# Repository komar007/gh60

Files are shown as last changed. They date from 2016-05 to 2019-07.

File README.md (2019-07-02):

# GH60
GH60 - an open-source mechanical keyboard PCB designed for the community at [geekhack](geekhack.org).

You can read more over [here](http://blog.komar.be/projects/gh60-programmable-keyboard/).



## Geekhack threads
- [[Prototyping] GH60 Keyboard](http://geekhack.org/index.php?topic=34959.0) - free discussion and chat about the project,
- [GH60 prototype betatesting](http://geekhack.org/index.php?topic=37570.0) - revision A bug reports,
- [GH60 rev. B betatesting](http://geekhack.org/index.php?topic=50685.0) - revision B bug reports,
- [GH60 Group Buy (PRODUCTION)](http://geekhack.org/index.php?topic=41464.0) - group buy organization and chat.

## Articles
- Introduction: [Introducing the GH60 keyboard project](http://blog.komar.be/?p=267)
- Changes in rev. B: [GH60 evolution](http://blog.komar.be/gh60-evolution/)
- Release of rev. C: [GH60 rev. C "plain edition" is out](http://blog.komar.be/gh60-rev-c-plain-edition-is-out/)

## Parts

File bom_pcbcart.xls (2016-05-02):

物料清单BOM
Manufacturer生产商 | Manufacturer Part Number生产商编号 | Designator位置 | Qty数量 | Description描述(值，耐压，精度μF) | Case 封装 | SMD ,BGA,LLC(QFN),OR TH | points点数 | points | Top/Bottom顶层/底层 | 厂家 | 厂家物料号 | 描述 | 采购备注 | MOQ10 | Customer reply
AVX | 08051A220KAT2A | C1, C2 | 2 | 22pF,100V,10%,C0G,0805 | 0805 | SMD | 2 | 4 | Bottom | AVX | 08051A220KAT2A
YAGEO | CC0805KKX7R8BB105 | C3, C8 | 2 | 1uF,25V,10%,X7R,0805 | 0805 | SMD | 2 | 4 | Bottom | YAGEO | CC0805KKX7R8BB105
YAGEO | CC0805KRX7R9BB104 | C4, C5, C6, C7 | 4 | 100nF,50V,10%,X7R,0805 | 0805 | SMD | 2 | 8 | Bottom | YAGEO | CC0805KRX7R9BB104
Yageo | RC0805JR-0722RL | R1, R2 | 2 | 22R,5%,1/8W,0805 | 0805 | SMD | 2 | 4 | Bottom | Yageo | RC0805JR-0722RL
Yageo | RC0805FR-0710KL | R3, R5 | 2 | 10K,1%,1/8W,0805 | 0805 | SMD | 2 | 4 | Bottom | Yageo | RC0805FR-0710KL
Crownpo | CD4148WS | D01, D02, D03, D04, D05, D06, D07, D08, D09, D10, D11, D12, D13, D14, D15, D16, D17, D18, D19, D21, D22, D23, D24, D26, D27, D28, D29, D30, D31, D32, D33, D34, D36, D37, D38, D39, D41, D42, D43, D44, D46, D47, D48, D49, D50, D51, D52, D53, D54, D55, D56, D57, D58, D59, D60, D61, D62, D63, D64, D65, D66, D67, D68, D69, D70 | 65 | 100V,150mA,0805 | 0805 | SMD | 2 | 130 | Bottom | Crownpo | CD4148WS
NDK | NX3225GA-16MHZ- STD-CRG-2 | X1 | 1 | 16MHz,8pF,4-SMD(3.2mmL*2.5mmW*0.9mmH) | 4-SMD | SMD | 4 | 4 | Bottom | NDK | NX3225GA-16MHZ- STD-CRG-2
Atmel | ATMEGA32U4-AUR | IC1 | 1 | ATMEGA32U4-AUR,44-TQFP | 44-TQFP | SMD | 44 | 44 | Bottom | Atmel | ATMEGA32U4-AU
C&K Components | Y17K20502FP LFS | S0 | 1 | 32VDC,0.05A,6.2mmL*6.2mmW*3.1mmH | 6.2mmL*6.2mmW*3.1mmH | SMD | 4 | 4 | Bottom | C&K Components | KSEM31G LFS
Molex | 0675031020 | J1 | 1 | USB 2.0 OTG,mini B,right angle | see link | SMD | 9 | 9 | Bottom | Molex | 675031020
 |  | All components assembled on bottom side.

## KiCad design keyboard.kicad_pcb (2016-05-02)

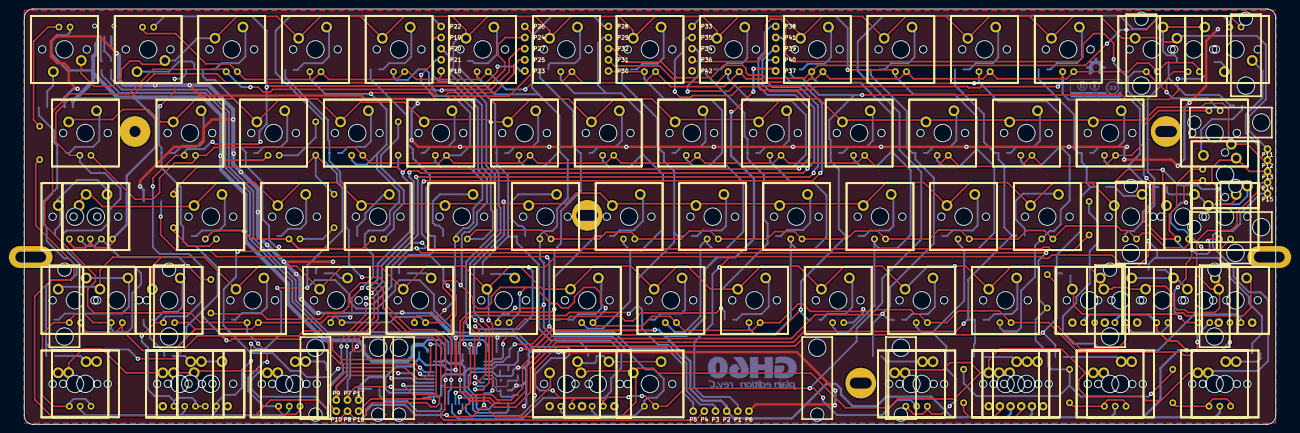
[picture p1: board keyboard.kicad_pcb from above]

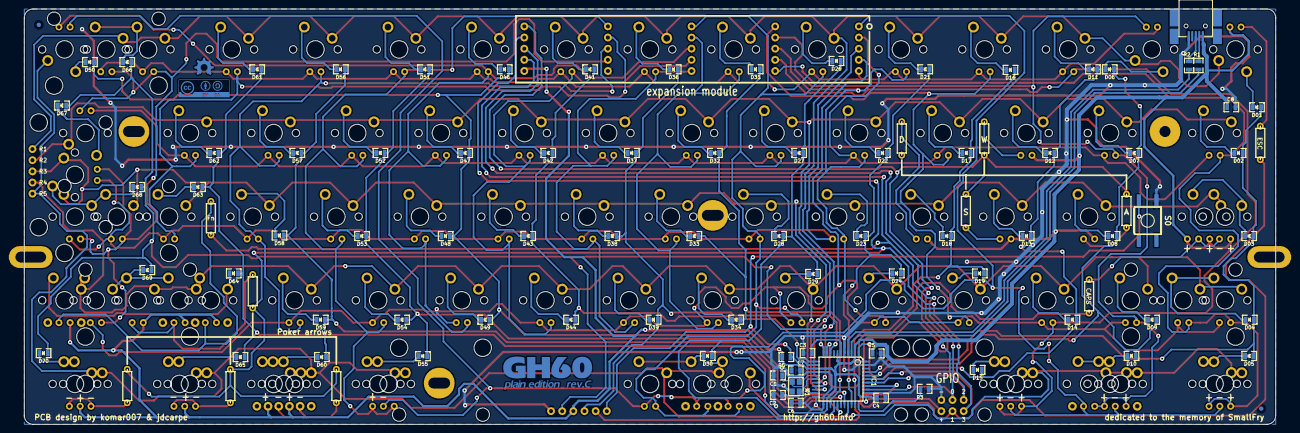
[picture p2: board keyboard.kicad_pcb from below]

Board: 2 copper layers, 285.0 x 94.6 mm, 335 parts (94 on the bottom side), 130 nets.

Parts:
C1, C2: 22p; 0805C
C3, C8: 1u; 0805C
C4, C5, C6, C7: 100n; 0805C
D01, D02, D03, D04, D05, D06, D07, D08, D09, D10, D11, D12, D13, D14, D15, D16, D17, D18, D19, D21, D22, D23, D24, D26, D27, D28, D29, D30, D31, D32, D33, D34, D36, D37, D38, D39, D41, D42, D43, D44, D46, D47, D48, D49, D50, D51, D52, D53, D54, D55, D56, D57, D58, D59, D60, D61, D62, D63, D64, D65, D66, D67, D68, D69, D70: 1N4148; 0805D
DB02, DB04, DB06, DB07, DB09, DB11, DB14, DB16, DB17, DB19, DB21, DB22, DB23, DB24, DB26, DB27, DB28, DB29, DB30, DB31, DB32, DB33, DB34, DB36, DB37, DB38, DB39, DB041, DB41, DB42, DB43, DB44, DB46, DB47, DB48, DB49, DB50, DB51, DB52, DB53, DB54, DB56, DB57, DB58, DB59, DB61, DB62, DB63, DB66, DB67, DB68, DB69, DB301, DB302, DB661, DB681, DB682: LED; MX1A-led_no3d
DB05, DB10, DB15, DB051, DB55, DB101, DB102, DB151, DB551: LEDa; MX1A-led
DC1, DC2: LED; MX1A-led_no3d
DC3: LED; MX1A-ledlock
DF3, DF10, DF11, DF20, DF201: LED; MX1A-led_no3d
DF21, DF22, DF23, DF211, DF221, DF231, DF232: LEDa; MX1A-led
DW1, DW2, DW3, DW4: LED; MX1A-led_no3d
FID: FIDUCIAL
FID#2: FIDUCIAL
HOLE: VAL**; PKRHSL
HOLE#2: VAL**; PKRHSL
HOLE#3, HOLE#4, HOLE#5: VAL**; PKRH
HOLE#6: VAL**; PKRHC
IC1: ATMEGA32U4; TQFP44
J1: MINI; 67503
MXST: VAL**; MXST
MXST#2, MXST#3, MXST#4, MXST#5, MXST#6, MXST#7, MXST#8, MXST#9, MXST#10, MXST#11, MXST#12, MXST#13, MXST#14, MXST#15: VAL**; MXST
MXWIRE: VAL**; MX1A-wire
MXWIRE#2, MXWIRE#3, MXWIRE#4, MXWIRE#5, MXWIRE#6, MXWIRE#7, MXWIRE#8, MXWIRE#9: VAL**; MX1A-wire
P1, P2, P3, P4, P5, P6, P7, P8, P9, P10, P11, P12, P13, P14, P15, P16, P17, P18, P19, P20, P21, P22, P23, P24, P25, P26, P27, P28, P29, P30, P31, P32, P33, P34, P35, P36, P37, P38, P39, P40, P41, P42: CONN_1; pad
R1, R2: 22; 0805R
R3, R5: 10k; 0805R
R4: 300; resistor
R6, R7, R8, R9, R10, R11, R12, R13, R14, R15: R; resistor
S0: DTSM-6; KSEM31GLFS
S01, S02, S03, S04, S05, S06, S07, S08, S10, S11, S12, S13, S14, S15, S16, S17, S18, S19, S21, S22, S23, S24, S26, S27, S28, S29, S30, S31, S32, S33, S34, S36, S37, S38, S39, S41, S42, S43, S44, S46, S47, S48, S49, S51, S52, S53, S54, S55, S56, S57, S58, S59, S60, S61, S62, S65, S66, S67, S68, S69, S70: MX1A
S09, S031, S041, S50, S63, S101, S102, S151, S301, S302, S0512, S552, S601, S602, S641, S661, S682, S691, S692, S6512, S7012: MX1Aa; MX1A_no3d
S64, S681: MX1A; MX1A_no3d
X1: ASX3F; 4-SMD

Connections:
/GPIO0: IC1.36, P7.1, P38.1, R6.1, R7.1, R8.1, R9.1
/GPIO1: IC1.37, P8.1, P39.1, R12.1
/GPIO2: IC1.38, P9.1, P40.1, R10.1
/GPIO3: IC1.39, P10.1, P41.1, R11.1, R13.1, R14.1, R15.1
/Leds/lcol1: DB02.1, DB04.1, DB05.1, DB041.1, DB051.1, P23.1
/Leds/lcol2: DB06.1, DB07.1, DB09.1, DB10.1, DB101.1, DB102.1, P24.1
/Leds/lcol3: DB11.1, DB14.1, DB15.1, DB151.1, P25.1
/Leds/lcol4: DB16.1, DB17.1, DB19.1, P26.1
/Leds/lcol5: DB21.1, DB22.1, DB23.1, DB24.1, P27.1
/Leds/lcol6: DB26.1, DB27.1, DB28.1, DB29.1, DB30.1, DB301.1, DB302.1, P28.1
/Leds/lcol7: DB31.1, DB32.1, DB33.1, DB34.1, P29.1
/Leds/lcol8: DB36.1, DB37.1, DB38.1, DB39.1, P30.1
/Leds/lcol9: DB41.1, DB42.1, DB43.1, DB44.1, P31.1
/Leds/lcol10: DB46.1, DB47.1, DB48.1, DB49.1, DB50.1, P32.1
/Leds/lcol11: DB51.1, DB52.1, DB53.1, DB54.1, DB55.1, DB551.1, P33.1
/Leds/lcol12: DB56.1, DB57.1, DB58.1, DB59.1, P34.1
/Leds/lcol13: DB61.1, DB62.1, DB63.1, P35.1
/Leds/lcol14: DB66.1, DB67.1, DB68.1, DB69.1, DB661.1, DB681.1, DB682.1, P36.1
/Leds/lrow1: DB06.2, DB11.2, DB16.2, DB21.2, DB26.2, DB31.2, DB36.2, DB41.2, DB46.2, DB51.2, DB56.2, DB61.2, DB66.2, DB661.2, P18.1
/Leds/lrow2: DB02.2, DB07.2, DB17.2, DB22.2, DB27.2, DB32.2, DB37.2, DB42.2, DB47.2, DB52.2, DB57.2, DB62.2, DB67.2, P19.1
/Leds/lrow3: DB23.2, DB28.2, DB33.2, DB38.2, DB43.2, DB48.2, DB53.2, DB58.2, DB63.2, DB68.2, DB681.2, DB682.2, P20.1
/Leds/lrow4: DB04.2, DB09.2, DB14.2, DB19.2, DB24.2, DB29.2, DB34.2, DB39.2, DB041.2, DB44.2, DB49.2, DB54.2, DB59.2, DB69.2, P21.1
/Leds/lrow5: DB05.2, DB10.2, DB15.2, DB30.2, DB50.2, DB55.2, DB102.2, DB301.2, DB302.2, P22.1
/Matrix/CAPS_LED: IC1.10, P4.1, R4.2
/Matrix/col1: D01.1, D02.1, D03.1, D04.1, D05.1, IC1.41
/Matrix/col2: D06.1, D07.1, D08.1, D09.1, D10.1, IC1.40
/Matrix/col3: D11.1, D12.1, D13.1, D14.1, D15.1, IC1.1
/Matrix/col4: D16.1, D17.1, D18.1, D19.1, IC1.32
/Matrix/col5: D21.1, D22.1, D23.1, D24.1, IC1.31
/Matrix/col6: D26.1, D27.1, D28.1, D29.1, D30.1, IC1.30
/Matrix/col7: D31.1, D32.1, D33.1, D34.1, IC1.25
/Matrix/col8: D36.1, D37.1, D38.1, D39.1, IC1.9, P3.1
/Matrix/col9: D41.1, D42.1, D43.1, D44.1, IC1.12
/Matrix/col10: D46.1, D47.1, D48.1, D49.1, D50.1, IC1.29
/Matrix/col11: D51.1, D52.1, D53.1, D54.1, D55.1, IC1.28
/Matrix/col12: D56.1, D57.1, D58.1, D59.1, D60.1, IC1.27
/Matrix/col13: D61.1, D62.1, D63.1, D64.1, D65.1, IC1.26
/Matrix/col14: D66.1, D67.1, D68.1, D69.1, D70.1, IC1.11, P1.1
/Matrix/row1: IC1.18, P11.1, S01.1, S06.1, S11.1, S16.1, S21.1, S26.1, S31.1, S36.1, S41.1, S46.1, S51.1, S56.1, S61.1, S66.1, S661.1
/Matrix/row2: IC1.19, P12.1, S02.1, S07.1, S12.1, S17.1, S22.1, S27.1, S32.1, S37.1, S42.1, S47.1, S52.1, S57.1, S62.1, S67.1
/Matrix/row3: IC1.20, P13.1, S03.1, S08.1, S13.1, S18.1, S23.1, S28.1, S031.2, S33.1, S38.1, S43.1, S48.1, S53.1, S58.1, S63.1, S68.1, S681.1, S682.2
/Matrix/row4: IC1.21, P14.1, S04.1, S09.1, S14.1, S19.1, S24.1, S29.1, S34.1, S39.1, S041.1, S44.1, S49.1, S54.1, S59.1, S64.2, S69.1, S641.1, S691.2, S692.1
/Matrix/row5: IC1.22, P15.1, S05.1, S10.1, S15.1, S30.1, S50.1, S55.1, S60.1, S65.1, S70.1, S101.1, S102.1, S151.1, S301.1, S302.1, S0512.1, S552.1, S601.1, S602.1, S6512.1, S7012.1
/~RES~: IC1.13, P5.1, R5.2, S0.3
GND: C1.2, C2.2, C3.2, C4.2, C5.2, C6.2, C7.2, C8.2, IC1.5, IC1.15, IC1.23, IC1.35, IC1.43, J1.5, P6.1, P17.1, P42.1, R3.2, S0.1, X1.2, X1.4
unnamed: C1.1, IC1.16, X1.1
unnamed: DW3.2, R8.2
unnamed: DW2.2, R7.2
unnamed: DW1.2, R6.2
unnamed: DW4.2, R9.2
unnamed: IC1.33, R3.1
unnamed: J1.3, R2.2
unnamed: J1.2, R1.2
unnamed: IC1.4, R2.1
unnamed: IC1.3, R1.1
unnamed: C3.1, IC1.6
unnamed: C2.1, IC1.17, X1.3
unnamed: DF22.2, DF221.2, R14.2
unnamed: DF3.2, R12.2
unnamed: DF10.2, DF11.2, R10.2
unnamed: DF23.2, DF231.2, R15.2
unnamed: DF20.2, DF201.2, R11.2
unnamed: DF21.2, DF211.2, R13.2
unnamed: D16.2, S16.2
unnamed: D27.2, S27.2
unnamed: D28.2, S28.2
unnamed: D29.2, S29.2
unnamed: D17.2, S17.2
unnamed: D18.2, S18.2
unnamed: D19.2, S19.2
unnamed: D41.2, S41.2
unnamed: D37.2, S37.2
unnamed: D38.2, S38.2
unnamed: D22.2, S22.2
unnamed: D43.2, S43.2
unnamed: D42.2, S42.2
unnamed: D46.2, S46.2
unnamed: D47.2, S47.2
unnamed: D23.2, S23.2
unnamed: D21.2, S21.2
unnamed: D31.2, S31.2
unnamed: D01.2, S01.2
unnamed: D33.2, S33.2
unnamed: D32.2, S32.2
unnamed: D36.2, S36.2
unnamed: D05.2, S05.2, S0512.2
unnamed: D15.2, S15.2, S151.2
unnamed: D55.2, S55.2, S552.2
unnamed: D51.2, S51.2
unnamed: D65.2, S65.2, S6512.2
unnamed: D12.2, S12.2
unnamed: D02.2, S02.2
unnamed: D07.2, S07.2
unnamed: D08.2, S08.2
unnamed: D13.2, S13.2
unnamed: D09.2, S09.2
unnamed: D14.2, S14.2
unnamed: D70.2, S70.2, S7012.2
unnamed: D03.2, S03.2, S031.1
unnamed: D26.2, S26.2
unnamed: D06.2, S06.2
unnamed: D11.2, S11.2
unnamed: D50.2, S50.2
unnamed: D63.2, S63.2
unnamed: D58.2, S58.2
unnamed: D53.2, S53.2
unnamed: D67.2, S67.2
unnamed: D52.2, S52.2
unnamed: D48.2, S48.2
unnamed: D44.2, S44.2
unnamed: D62.2, S62.2
unnamed: D49.2, S49.2
unnamed: D54.2, S54.2
unnamed: D59.2, S59.2
unnamed: D57.2, S57.2
unnamed: D61.2, S61.2
unnamed: D56.2, S56.2
unnamed: D24.2, S24.2
unnamed: D34.2, S34.2
unnamed: D39.2, S39.2
unnamed: D68.2, S68.2, S681.2, S682.1
unnamed: D10.2, S10.2, S101.2, S102.2
unnamed: D30.2, S30.2, S301.2, S302.2
unnamed: D04.2, S04.2, S041.2
unnamed: D64.2, S64.1, S641.2
unnamed: D69.2, S69.2, S691.1, S692.2
unnamed: DC1.2, DC2.2, R4.1
unnamed: D60.2, S60.2, S601.2, S602.2
unnamed: D66.2, S66.2, S661.2
VCC: C4.1, C5.1, C6.1, C7.1, C8.1, DC1.1, DC2.1, DC3.1, DF3.1, DF10.1, DF11.1, DF20.1, DF21.1, DF22.1, DF23.1, DF201.1, DF232.1, DW1.1, DW2.1, DW3.1, DW4.1, IC1.2, IC1.7, IC1.14, IC1.24, IC1.34, IC1.44, J1.1, P2.1, P16.1, P37.1, R5.1

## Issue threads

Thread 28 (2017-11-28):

bug and puzzles with gh60's kicad sch file

243750496, 2017-11-28:
Q1:why setting up an no-using page(led.sch)
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

Q2:and there is a bug here
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

Q3:why you draw something like P11-15 with no line connect it?same as led part(in led.sch)
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

btw:i use gh60-revC_plain

TweetyDaBird, 2020-11-17:
Q1: It's very clearly used for the backligth LED's...
Q2: Not a bug, just KiCad's way of saying it doesn't know if GND has power or not (useful only if you are running a simulation)
Q3: They are pulled out to the edge of the board, most likely for expansion...

komar007, 2020-11-17:
Well, it looks I overlooked this issue 3 years ago:D
Thanks @TweetyDaBird, I think my answers would be exactly the same;)

Closed 2020-11-17.

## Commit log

2012-09-02 cleaning up...
    [keyboard.brd, keyboard.sch, matrix.sch]
2012-09-02 added libs
    [keyboard.sch, matrix.sch]
2012-09-02 removed crap
    [keyboard.brd]
2012-09-02 some preliminary routing
    [keyboard.brd]
2012-09-02 additional routing, fixes
    [keyboard.brd]
2012-09-13 fixed usb socket position and MX1A drill sizes
    [keyboard.brd]
2012-09-13 fixed positions again, added measurements
    [keyboard.brd, keyboard.sch, matrix.sch]
2012-09-13 horizontal alignment done
    [keyboard.brd, keyboard.sch, matrix.sch]
2012-09-13 routed matrix
    [keyboard.brd, keyboard.sch, matrix.sch]
2012-09-21 some minor changes
    [keyboard.brd, keyboard.sch, matrix.sch]
2012-10-03 added diodes
    [keyboard.brd, keyboard.sch, matrix.sch]
2012-10-07 vertical dimensions corrected, a couple of other fixes
    [keyboard.brd, keyboard.sch, matrix.sch]
2012-10-09 fixed switch spacing
    [keyboard.brd]
2012-10-10 set proper dimensions of pcb, moved holes to fit poker case
    [keyboard.brd]
2012-10-11 some small changes
    [keyboard.brd, keyboard.sch, matrix.sch]
2012-10-15 added reset button, filled component info
    [keyboard.brd, keyboard.sch, matrix.sch]
2012-10-16 cosmetic chanages, silkscreen, new usb con
    [keyboard.brd, keyboard.sch, matrix.sch]
2012-10-16 silkscreen modifications
    [keyboard.brd, keyboard.sch, matrix.sch]
2012-10-16 added component details
    [keyboard.brd, keyboard.sch, matrix.sch]
2012-10-23 enhanced crystal layout, added ground pours
    [keyboard.brd, keyboard.sch, matrix.sch]
2012-10-23 added 1.25 enter support
    [keyboard.brd, keyboard.sch, matrix.sch]
2012-10-24 added one missing connection
    [keyboard.brd, keyboard.sch, matrix.sch]
2012-10-24 added isp connector
    [keyboard.brd, keyboard.sch, matrix.sch]
2012-10-25 added missing files to the repo
    [keyboard.brd, keyboard.sch, matrix.sch]
2012-10-26 artwork stuff
    [keyboard.brd, keyboard.sch, matrix.sch]
2012-10-29 added oshw logo, fix one ratsnet, shrunk solder paste
    [keyboard.brd]
2012-10-31 cosmetic changes
    [keyboard.brd]
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2012-10-31 more corrections
    [keyboard.brd]
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2013-01-09 set X1, J0, S0 to be exported to position file
    [keyboard.brd]
2013-01-22 fixed C3 problem
    [keyboard.brd]
2013-02-11 changed revision label to "rev. B"
    [keyboard.brd]
2013-03-06 added row breakout pins, rotated switches
    [keyboard.brd, keyboard.sch, matrix.sch]
2013-03-06 added split backspace option
    [keyboard.brd, keyboard.sch, matrix.sch]
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2013-03-23 added fixing wire module
    for better grip in some switches without fixing pins
2013-04-05 (#1, #2) unrotated switches and added LED pads
    [keyboard.brd, keyboard.sch, matrix.sch]
2013-04-16 (#7) added wasd resistor and connected to GPIO0
    [keyboard.brd, keyboard.sch, matrix.sch]
2013-04-18 (#4) moved top-left and top-right and center holes 0.4mm to the right
    Also fixed bottom hole by moving 0.2mm to the left
    [keyboard.brd]
2013-04-18 (#4) moved all the holes up by 0.25mm
    This moves the board down, centering the switches and keycaps
    vertically.
    [keyboard.brd]
2013-04-24 (#4) bottom hole 0.3mm to the right - fix after physical examination
    [keyboard.brd]
2013-04-25 (#12) fixed usb receptacle position - moved 0.75 to the right
    [keyboard.brd]
2013-04-25 (#9) switched to natconn USB receptacle
    [keyboard.brd]
2013-04-25 (#4) moved all holes another 0.15mm up, this seems to be better centered
    [keyboard.brd]
2013-04-25 (#5) enlarged the board vertically
    0.3mm more on the top and 0.3mm on the bottom
    [keyboard.brd]
2013-04-25 (#8) moved some labels around, flipped wasd resistors
    [keyboard.brd]
2013-04-25 (#13) added right Fn led
    [keyboard.brd, keyboard.sch, matrix.sch]
2013-04-25 (#13) added left Fn led
    [keyboard.brd, keyboard.sch, matrix.sch]
2013-04-25 (#13) added also ESC led
    [keyboard.brd, keyboard.sch, matrix.sch]
2013-04-25 (#13) also connected the other right Fn (left of shift)
    [keyboard.brd, keyboard.sch, matrix.sch]
2013-04-25 (#14) added LED pads to S692
    [keyboard.brd]
2013-05-05 (#13) added Poker-like arrow led cluster
    [keyboard.brd, keyboard.sch, matrix.sch]
2013-05-05 (#9) changed USB receptacle's description in the schematic
    [keyboard.sch, matrix.sch]
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2013-05-23 added most of led traces
    [keyboard.brd, keyboard.sch, matrix.sch]
2013-06-19 routed most of remaining LEDs
    [keyboard.brd, keyboard.sch, matrix.sch]
2013-06-21 routed led cols and rows to headers
    [keyboard.brd, keyboard.sch, matrix.sch]
2013-06-21 cosmetic corrections
    [keyboard.brd, keyboard.sch, matrix.sch]
2013-06-27 Added vertical bar keepouts
    [keyboard.brd]
2013-06-27 moved the backlight expansion header
    so that the pads are centered between the switches
    [keyboard.brd]
2013-06-27 (#20) set LED drill size to 0.8128mm
    [keyboard.brd, keyboard.sch, matrix.sch]
2013-06-27 (#20) changed resistor pad size to 1.6mm
    [keyboard.brd]
2013-06-27 (#20) fixed mxwire drill size
    [keyboard.brd]
2013-06-27 (#20) changed goldpin pads sizes to 1.8mm
    [keyboard.brd]
2013-06-27 (#22) moved some SMD diodes
    [keyboard.brd]
2013-06-27 (#16) routed GPIOs to the expansion connector
    [keyboard.brd, keyboard.sch, matrix.sch]
2013-06-27 added one missing bar keepout
    [keyboard.brd]
2013-06-27 (#16) removed all 8mil traces and substituted with default
    [keyboard.brd]
2013-06-27 (#3) updated GH60 logo, cleaned up the generation scripts
    [keyboard.brd]
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2013-07-01 (#18) filled Back with GND
    [keyboard.brd]
2013-07-01 (#10) changed footprint of the reset switch
    [keyboard.brd]
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2013-07-05 (#9) changed USB connector to a different molex
    [keyboard.brd, keyboard.sch, leds.sch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]
2013-07-05 (#15) fixed THT resistors' positions
    [keyboard.brd]
2013-07-07 (#17) fixed the position of USB receptacle
    also rounded the dimensions to 0.1mm
    [keyboard.brd]
2013-07-07 fixed silkscreen
    [keyboard.brd]
2013-07-07 (#23) added 4 remaining LED pads
    [keyboard.brd, keyboard.sch, leds.sch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]
2013-07-07 added board dimensions and 2 svg scripts
    [keyboard.brd]
2013-07-07 (#8) moved some components and enhanced the silkscreen
    [keyboard.brd]
2013-07-08 (#8) added polarity markings on some LEDs
    [keyboard.brd]
2013-07-08 (#24) moved S0 according to visual inspection of rev. A
    [keyboard.brd]
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2013-07-16 changed col9 from PB0 to PB7
    [keyboard.brd, keyboard.sch, leds.sch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]
2013-07-16 moved C8 down, so that it doesn't interfere with a bar
    [keyboard.brd]
2013-07-16 moved R3 out of the way
    [keyboard.brd]
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2016-05-02 updated to rev. C "plain edition"
    Upgraded the files to the new version of KiCad.
    [keyboard.brd, keyboard.kicad_pcb, keyboard.sch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]
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2016-05-02 tweaked the dimensions layer
    [keyboard.kicad_pcb]
